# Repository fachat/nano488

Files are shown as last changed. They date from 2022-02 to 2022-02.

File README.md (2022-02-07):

# nano488

An IEEE488 interface for the PC using USB and an Arduino Nano (tm)

## Design

This IEEE488 interfaces uses an Arduino Nano (tm) and its serial-over-USB interface to have a PC control the IEEE488 interface.

The design is made to be able to work as both, a controller or a device, but the main purpose is to work as
a disk drive for the Commodore PET computers.

The design is inspired by https://github.com/Twilight-Logic/AR488 but I had to rearrange some lines to
add the Commodore disk drive's ATNA response circuit.

Also, the design uses the standards compliant 75160/75161 IEEE488 drivers, so electrical specifications are met.

Note, that no extra power supply line e.g. to the tape port is required, as the board is using the 5V
supplied by the USB bus connector (via the Arduino nano (tm))

## Software

The software that supports the disk drive functionality is XD2031 ( https://github.com/fachat/XD2031 ) - for details see there.

## Boards

### V1.1B

This board has four IEEE488 connectors:

1. a board edge connector similar to the Commodore PET IEEE488 connector
2. a slot connector to plug the device directly onto the Commodore PET IEEE488 connector
3. a 24 pin standards IEEE488 connector for standard IEEE488 stacking cables
4. a 24 pin flat ribbon connector

Here are the design files:

- [Eagle schematics](v1.1b/nano_ieee488_v1.1b.sch)
- [Eagle layout](v1.1b/nano_ieee488_v1.1b.brd)
- [Schematics picture](v1.1b/nano_ieee488_v1.1b-sch.png)
- [Board parts layout](v1.1b/nano_ieee488_v1.1b-layout.png)
- [Board full layout](v1.1b/nano_ieee488_v1.1b-brd.png)
- [Gerber files](v1.1b/nano_ieee488_v1.1b-gerbers.zip)

### V1.0B

This board has four IEEE488 connectors:

1. a board edge connector similar to the Commodore PET IEEE488 connector
1. a 24 pin standards IEEE488 connector for standard IEEE488 stacking cables
1. a 24 pin flat ribbon connector

Here are the design files:

- [Eagle schematics](v1.0b/nano_ieee488_v1.0b.sch)
- [Eagle layout](v1.0b/nano_ieee488_v1.0b.brd)
- [Schematics picture](v1.0b/nano_ieee488_v1.0b-sch.png)
- [Board parts layout](v1.0b/nano_ieee488_v1.0b-layout.png)
- [Board full layout](v1.0b/nano_ieee488_v1.0b-brd.png)

## Gallery

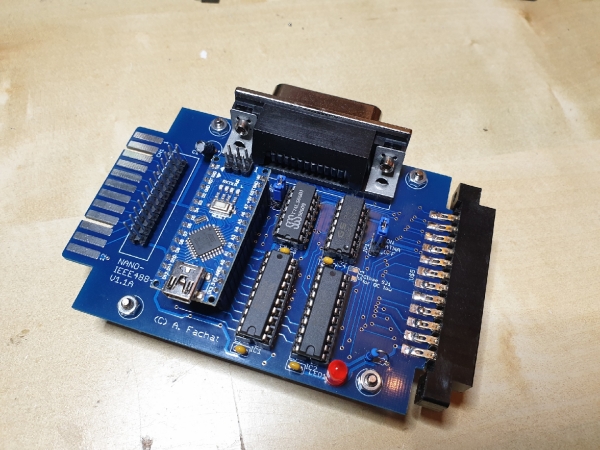
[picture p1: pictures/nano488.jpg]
Nano-488


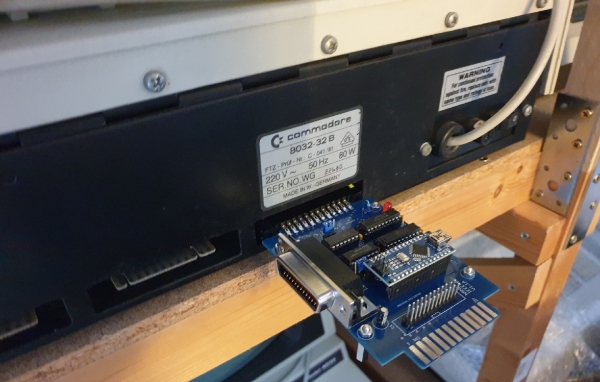
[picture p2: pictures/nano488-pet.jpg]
Nano-488 at a Commodore PET


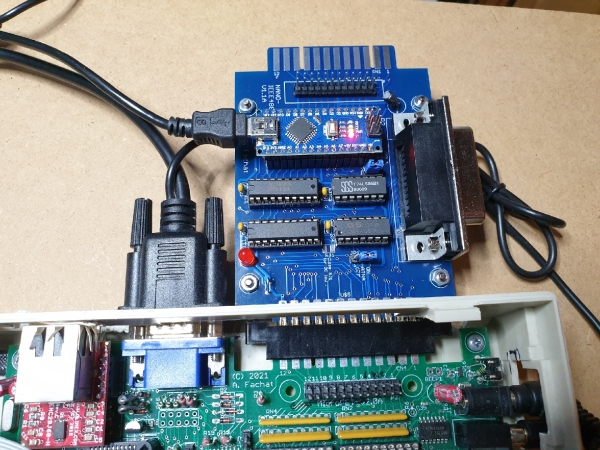
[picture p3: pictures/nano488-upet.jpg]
Nano-488 at a Micro-PET


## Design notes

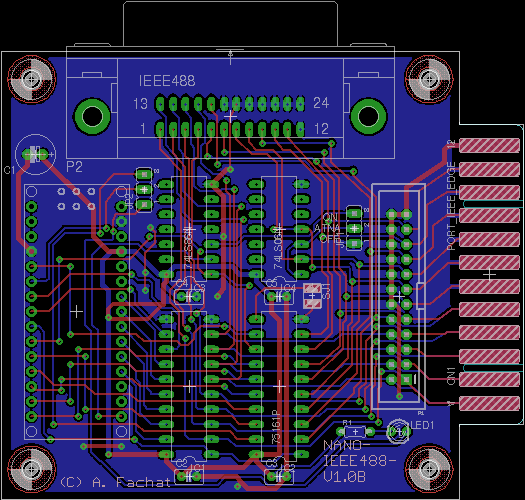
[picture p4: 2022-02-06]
v1.0b/nano_ieee488_v1.0b-brd.png

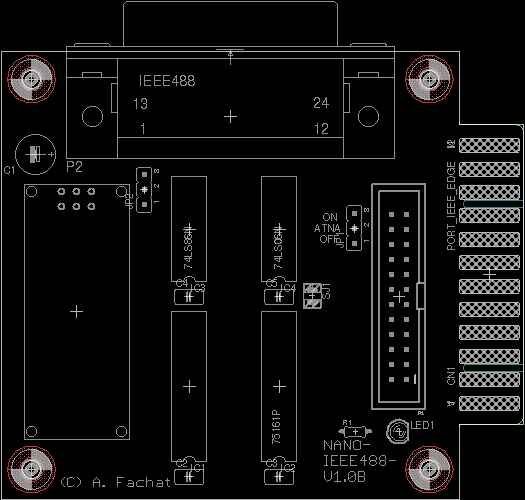
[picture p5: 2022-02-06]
v1.0b/nano_ieee488_v1.0b-layout.png

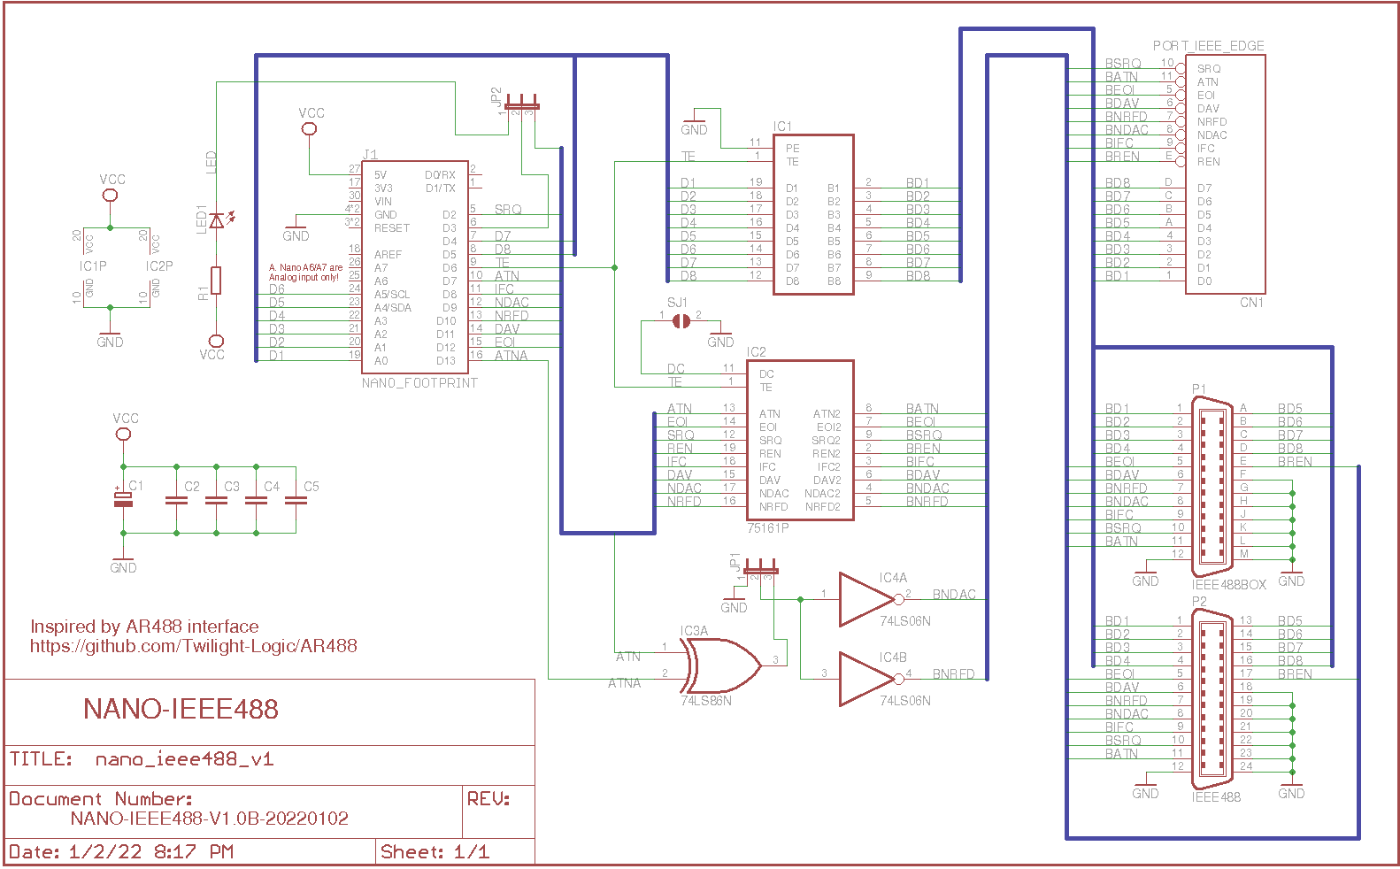
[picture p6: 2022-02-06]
v1.0b/nano_ieee488_v1.0b-sch.png

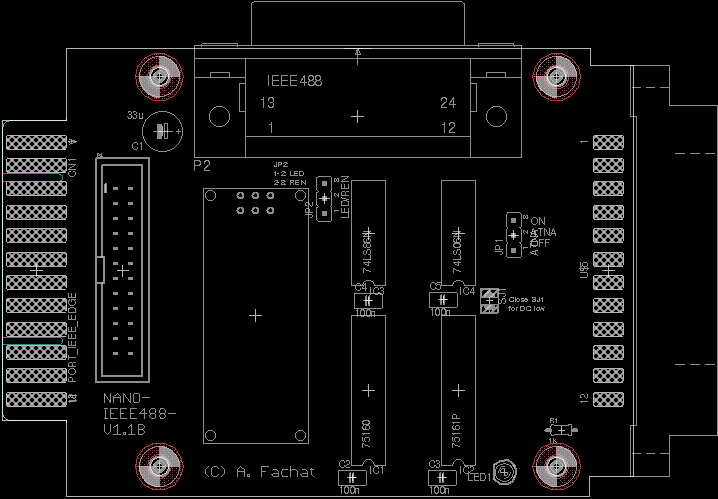
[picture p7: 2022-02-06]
v1.1b/nano_ieee488_v1.1b-layout.png

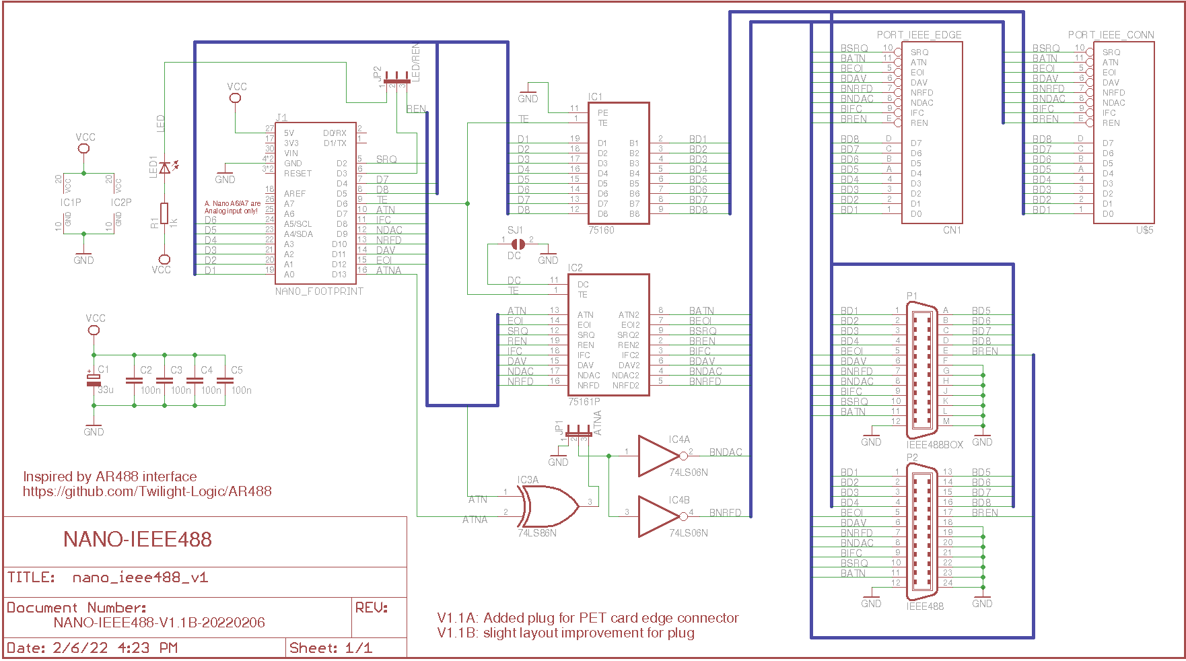
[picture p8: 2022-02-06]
v1.1b/nano_ieee488_v1.1b-sch.png

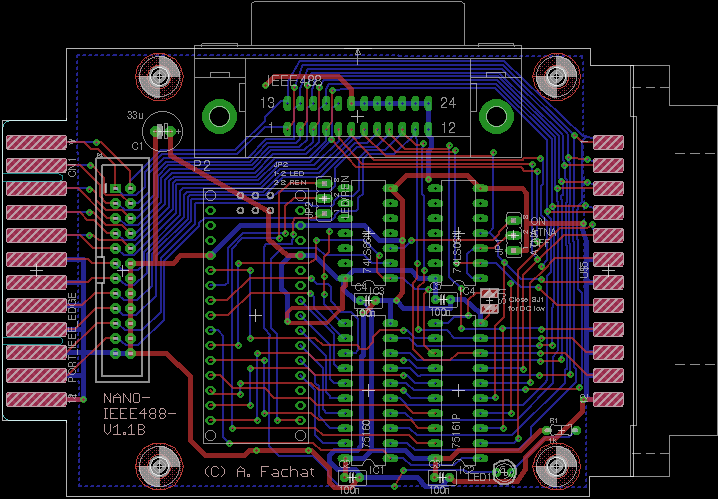
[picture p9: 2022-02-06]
v1.1b/nano_ieee488_v1.1b-brd.png

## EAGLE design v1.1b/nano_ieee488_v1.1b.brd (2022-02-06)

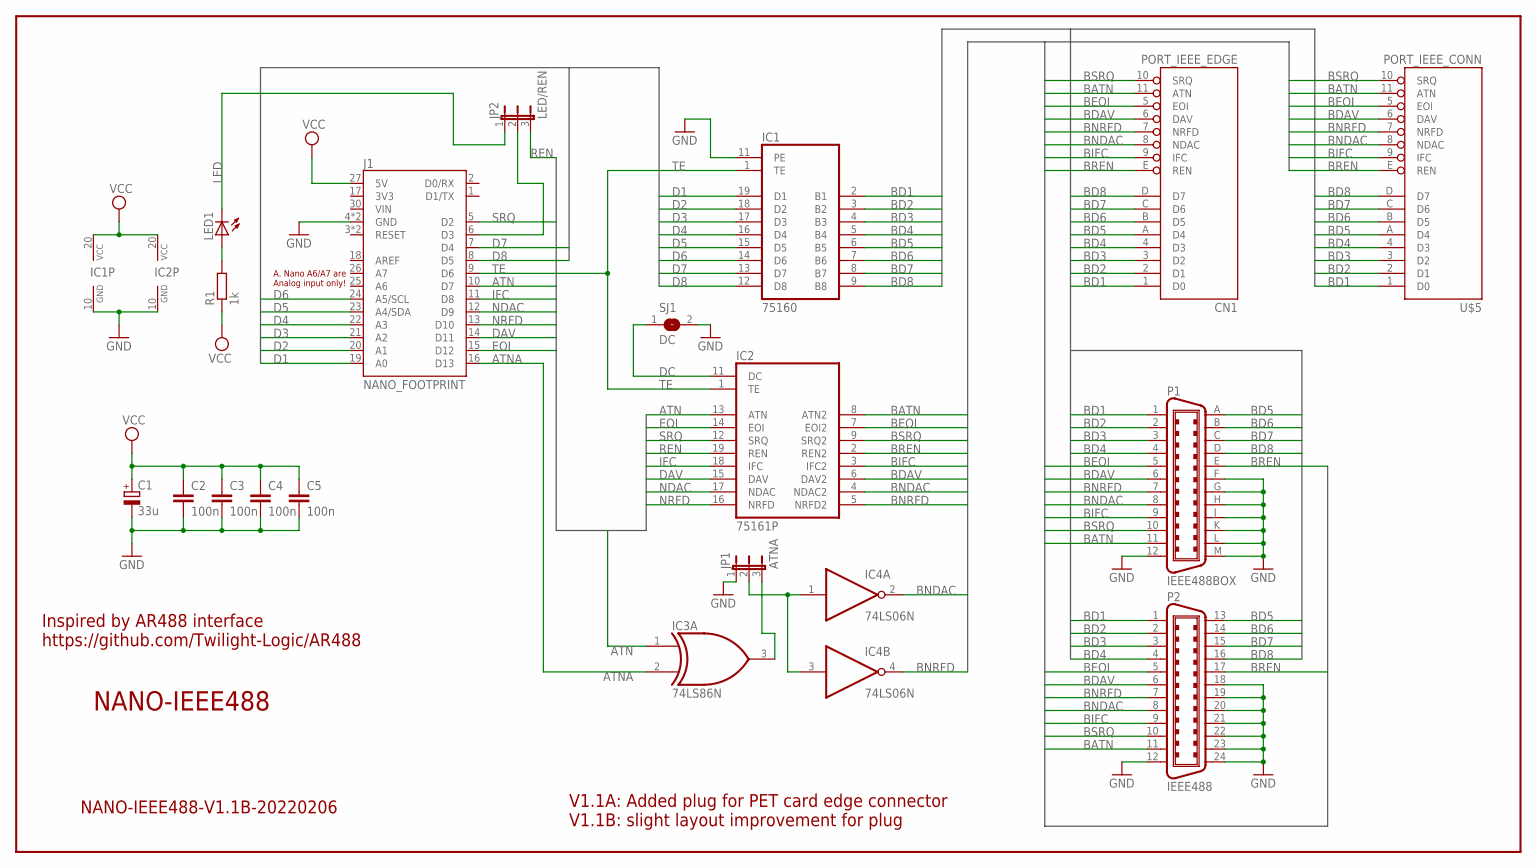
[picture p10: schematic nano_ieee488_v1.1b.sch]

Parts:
C1: 33u; E2,5-7
C2, C3, C4, C5: 100n; C025-025X050
CN1: PORT_IEEE_EDGE; MA156_12-2_IEEE
IC1: 75160; DIL20
IC2: 75161P; DIL20
IC3: 74LS86N; DIL14
IC4: 74LS06N; DIL14
J1: NANO_FOOTPRINT; NANO
JP1: ATNA; JP2
JP2: LED/REN; JP2
LED1: LED3MM
P1: IEEE488BOX; FLAT24BOX
P2: IEEE488; 24HP
R1: 1k; 0204/5
SJ1: DC; SJW
U$5: PORT_IEEE_CONN; MA156_12-2_SHORT

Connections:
ATN: IC2.13 (ATN), IC3.1 (I0), J1.10 (D7)
ATNA: IC3.2 (I1), J1.16 (D13)
BATN: CN1.11 (ATN), IC2.8 (ATN2), P1.11, P2.11, U$5.11 (ATN)
BD1: CN1.1 (D0), IC1.2 (B1), P1.1, P2.1, U$5.1 (D0)
BD2: CN1.2 (D1), IC1.3 (B2), P1.2, P2.2, U$5.2 (D1)
BD3: CN1.3 (D2), IC1.4 (B3), P1.3, P2.3, U$5.3 (D2)
BD4: CN1.4 (D3), IC1.5 (B4), P1.4, P2.4, U$5.4 (D3)
BD5: CN1.A (D4), IC1.6 (B5), P1.A (13), P2.13, U$5.A (D4)
BD6: CN1.B (D5), IC1.7 (B6), P1.B (14), P2.14, U$5.B (D5)
BD7: CN1.C (D6), IC1.8 (B7), P1.C (15), P2.15, U$5.C (D6)
BD8: CN1.D (D7), IC1.9 (B8), P1.D (16), P2.16, U$5.D (D7)
BDAV: CN1.6 (DAV), IC2.6 (DAV2), P1.6, P2.6, U$5.6 (DAV)
BEOI: CN1.5 (EOI), IC2.7 (EOI2), P1.5, P2.5, U$5.5 (EOI)
BIFC: CN1.9 (IFC), IC2.3 (IFC2), P1.9, P2.9, U$5.9 (IFC)
BNDAC: CN1.8 (NDAC), IC2.4 (NDAC2), IC4.2 (O), P1.8, P2.8, U$5.8 (NDAC)
BNRFD: CN1.7 (NRFD), IC2.5 (NRFD2), IC4.4 (O), P1.7, P2.7, U$5.7 (NRFD)
BREN: CN1.E (REN), IC2.2 (REN2), P1.E (17), P2.17, U$5.E (REN)
BSRQ: CN1.10 (SRQ), IC2.9 (SRQ2), P1.10, P2.10, U$5.10 (SRQ)
D1: IC1.19 (D1), J1.19 (A0)
D2: IC1.18 (D2), J1.20 (A1)
D3: IC1.17 (D3), J1.21 (A2)
D4: IC1.16 (D4), J1.22 (A3)
D5: IC1.15 (D5), J1.23 (A4/SDA)
D6: IC1.14 (D6), J1.24 (A5/SCL)
D7: IC1.13 (D7), J1.7 (D4)
D8: IC1.12 (D8), J1.8 (D5)
DAV: IC2.15 (DAV), J1.14 (D11)
DC: IC2.11 (DC), SJ1.1
EOI: IC2.14 (EOI), J1.15 (D12)
GND: C1.-, C2.2, C3.2, C4.2, C5.2, CN1.12 (GND), CN1.F (GND), CN1.H (GND), CN1.J (GND), CN1.K (GND), CN1.L (GND), CN1.M (GND), CN1.N (GND), IC1.10 (GND), IC1.11 (PE), IC2.10 (GND), IC3.7 (GND), IC4.7 (GND), J1.4 (GND), J1.29 (GND), JP1.1, P1.12, P1.F (18), P1.G (19), P1.H (20), P1.J (21), P1.K (22), P1.L (23), P1.M (24), P2.12, P2.18, P2.19, P2.20, P2.21, P2.22, P2.23, P2.24, SJ1.2, U$5.12 (GND), U$5.F (GND), U$5.H (GND), U$5.J (GND), U$5.K (GND), U$5.L (GND), U$5.M (GND), U$5.N (GND)
IFC: IC2.18 (IFC), J1.11 (D8)
LED: JP2.1, LED1.K (C)
unnamed: IC3.3 (O), JP1.3
unnamed: IC4.1 (I), IC4.3 (I), JP1.2
unnamed: LED1.A, R1.2
unnamed: J1.6 (D3), JP2.2
NDAC: IC2.17 (NDAC), J1.12 (D9)
NRFD: IC2.16 (NRFD), J1.13 (D10)
REN: IC2.19 (REN), JP2.3
SRQ: IC2.12 (SRQ), J1.5 (D2)
TE: IC1.1 (TE), IC2.1 (TE), J1.9 (D6)
VCC: C1.+, C2.1, C3.1, C4.1, C5.1, IC1.20 (VCC), IC2.20 (VCC), IC3.14 (VCC), IC4.14 (VCC), J1.27 (5V), R1.1

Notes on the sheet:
NANO-IEEE488
NANO-IEEE488-V1.1B-20220206
Inspired by AR488 interface https://github.com/Twilight-Logic/AR488
A. Nano A6/A7 are Analog input only!
V1.1A: Added plug for PET card edge connector V1.1B: slight layout improvement for plug

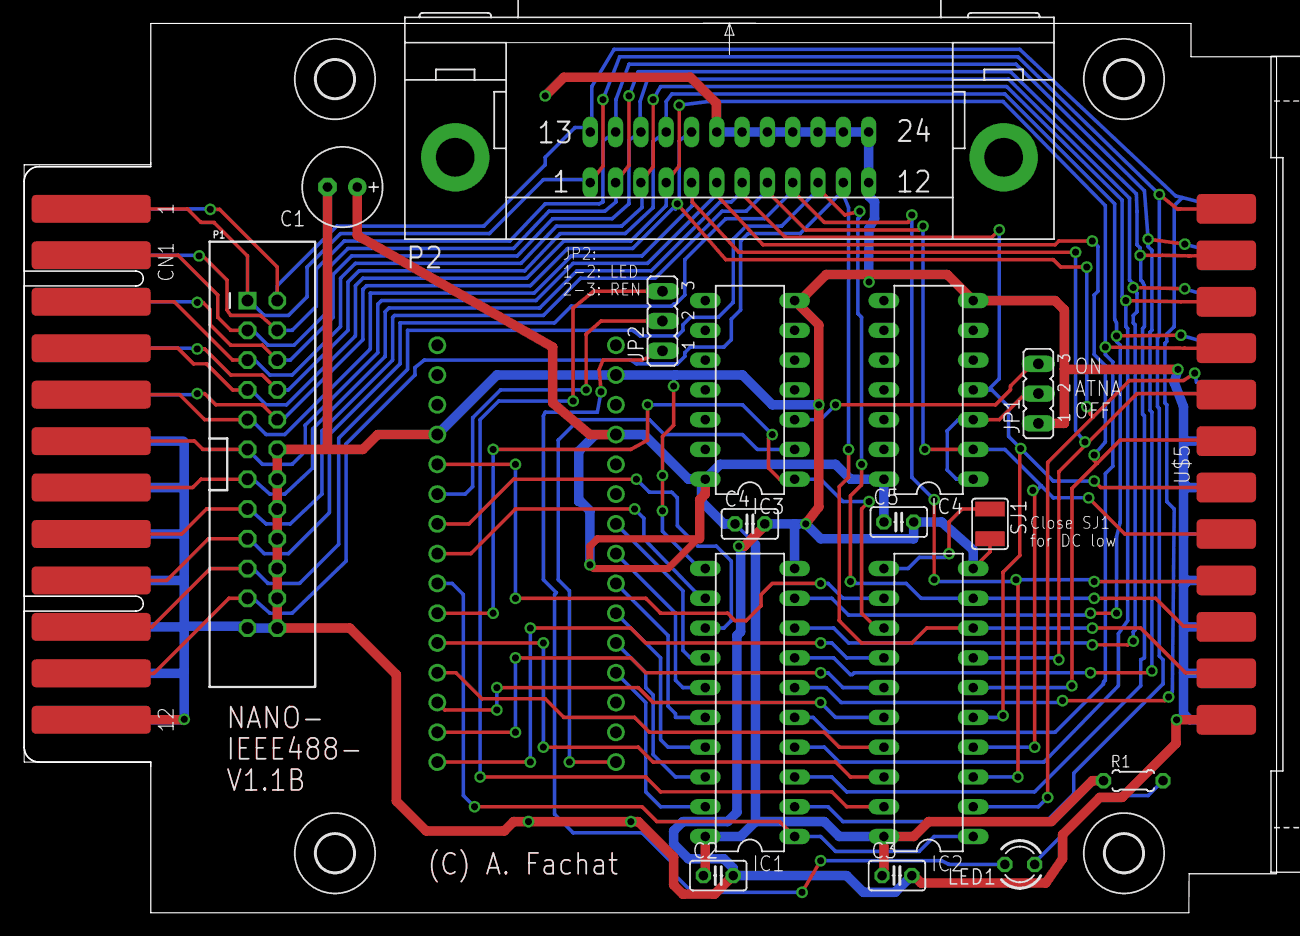
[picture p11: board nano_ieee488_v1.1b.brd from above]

Board: 2 copper layers, 106.8 x 75.9 mm, 23 parts (0 on the bottom side), 42 nets.

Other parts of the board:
U$1, U$2, U$3, U$4: 3,2

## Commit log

2022-02-06 initial commit, with v1.0b and v1.1b
    [nano_ieee488_v1.0b.brd, nano_ieee488_v1.0b.sch, nano_ieee488_v1.1b.brd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]
2022-02-07 add gerbers

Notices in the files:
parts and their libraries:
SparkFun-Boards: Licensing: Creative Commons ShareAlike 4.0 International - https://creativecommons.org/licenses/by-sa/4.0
